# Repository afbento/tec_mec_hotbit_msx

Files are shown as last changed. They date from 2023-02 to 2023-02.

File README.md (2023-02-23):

# Teclado mecânico no Hotbit - MSX

Aqui mostro detalhes da adaptação de teclado de membrama para teclado com switches de teclado mecânico, feita para o microcomputador Hotbit HB-8000 (padrão MSX).

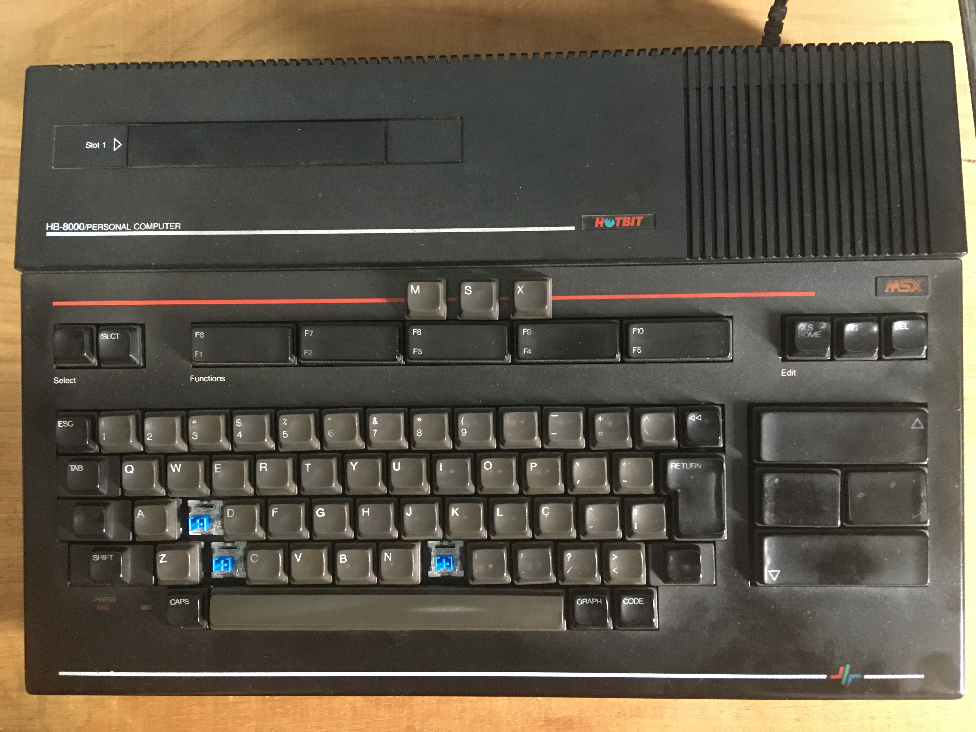
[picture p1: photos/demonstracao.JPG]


## Apresentação

ineficácia do teclado original (membrana). moda e desejo de muitos de um teclado mecânico pro Hotbit. compatibilidade quase ideal das teclas originais com switches (dust proof)

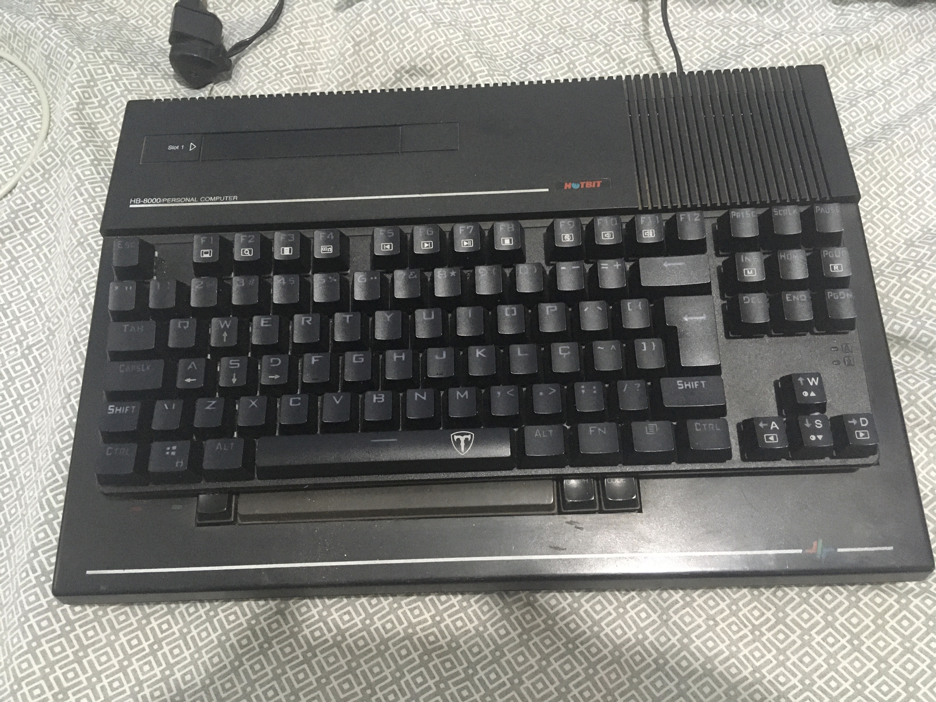
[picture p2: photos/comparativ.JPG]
 
Comparando o Hotbit com um teclado mecânico, doador das switches para esse projeto.

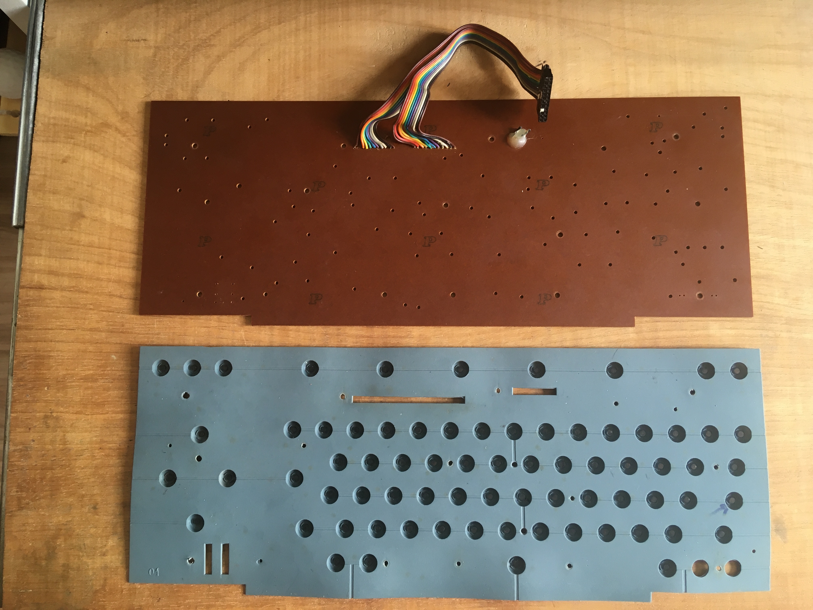
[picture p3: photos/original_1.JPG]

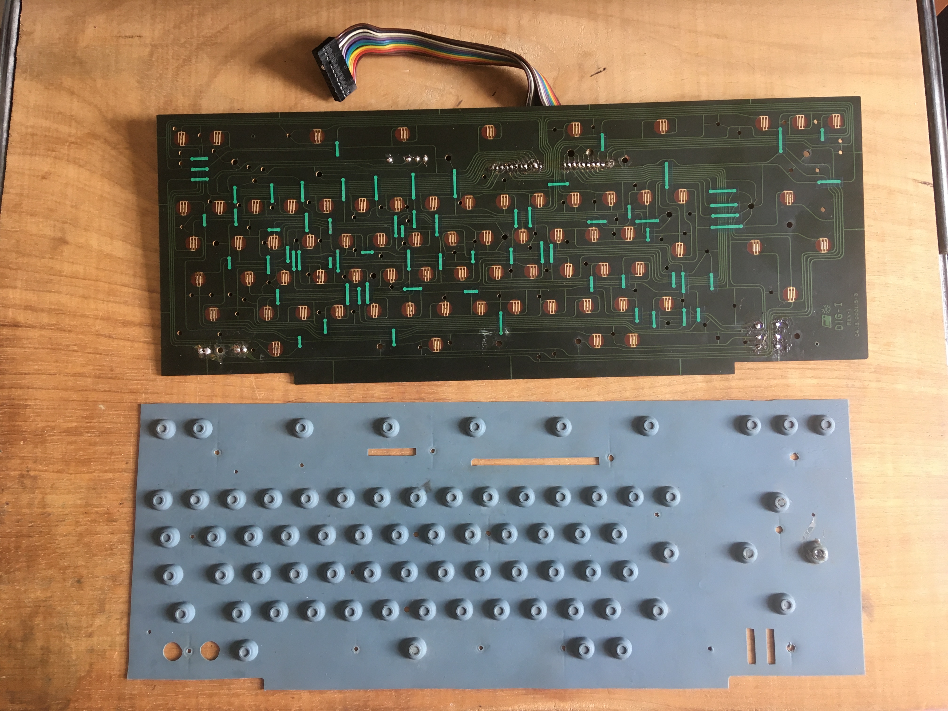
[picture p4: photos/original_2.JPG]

Membrana e PCB originais do Hotbit.

## Estudos

medidas e desenho feito em CAD como esboço pra possível corte em CNC, foi concluído um alto custo da confecção da base do teclado por esse método. além da confecção de PCB personalizada

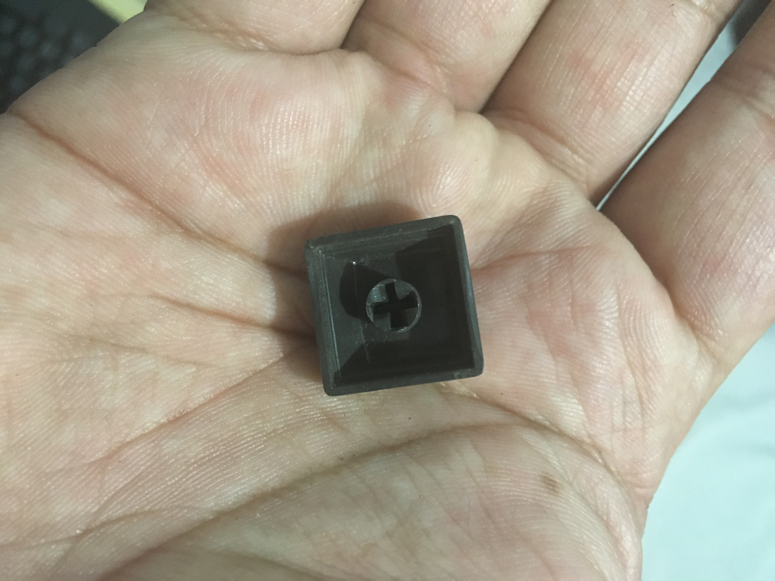
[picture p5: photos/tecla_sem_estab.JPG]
 Encaixe de tecla que não usa estabilizador

 
Conjunto tecla (sem estabilizador) e switch

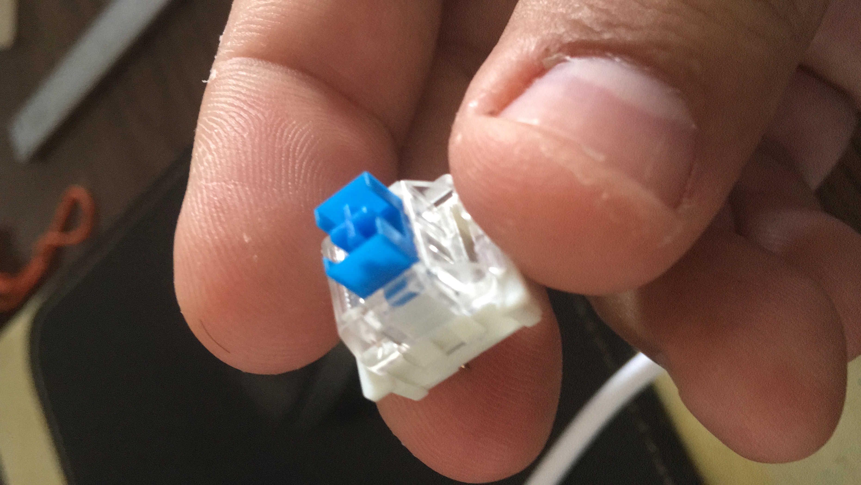
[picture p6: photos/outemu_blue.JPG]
 Switch Outemu Blue dust-proof

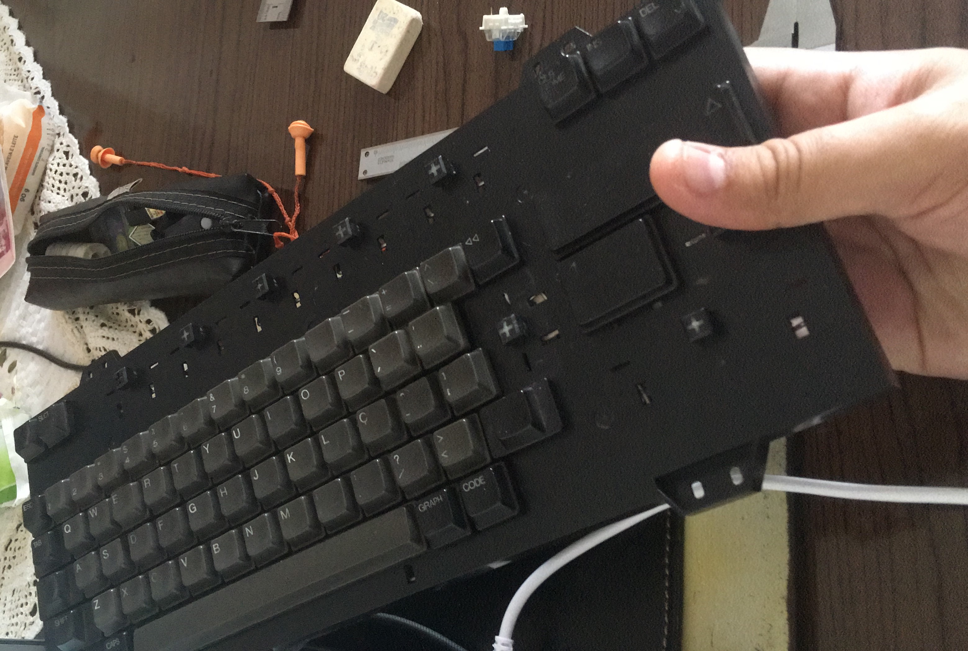
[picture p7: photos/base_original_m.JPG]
 Medindo a base original do teclado com paquímetro e no "olhômetro".

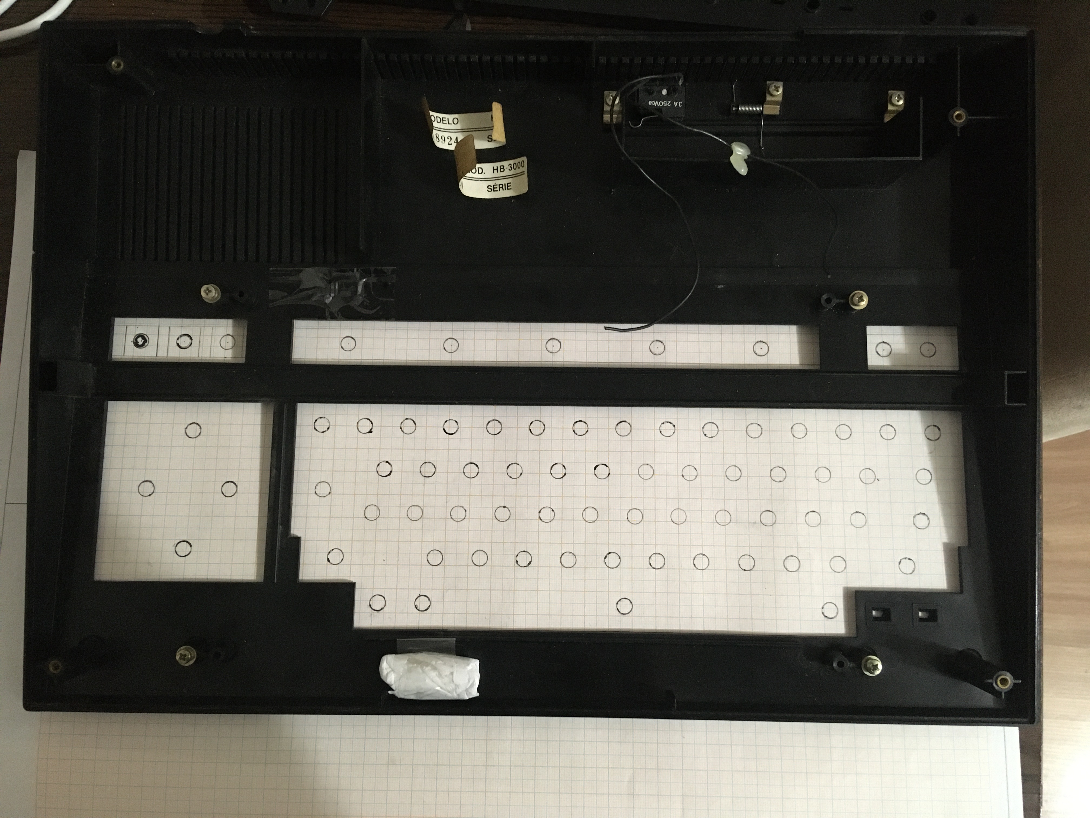
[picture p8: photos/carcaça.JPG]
 Carcaça do Hotbit junto com esboço feito com posição aproximada do centro de cada tecla

## Solução mais barata

idealização de um gabarito impresso em 3D que encaixa nos furos das teclas da base original do teclado do Hotbit, para execução de furos quadrados de 14mm x 14mm de maneira artesanal

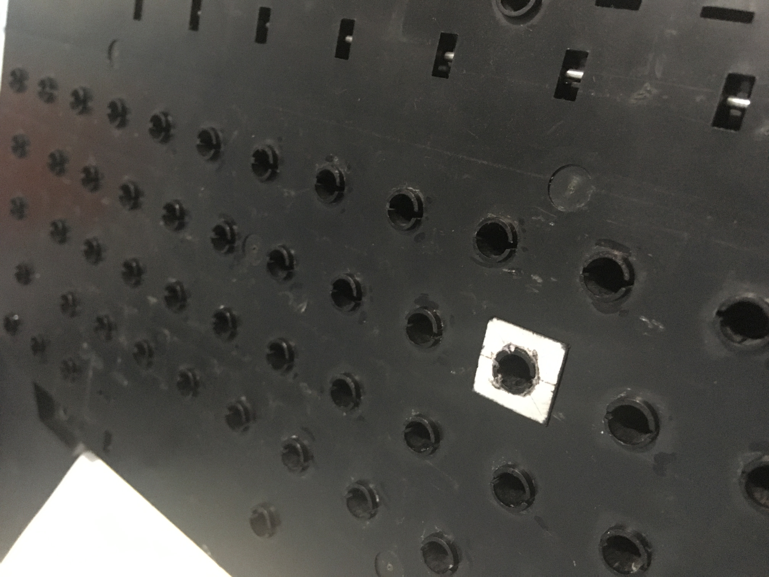
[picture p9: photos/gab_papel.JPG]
 Gabarito para traçar o furo quadrado em cada tecla, feito em papel (não foi utilizado)

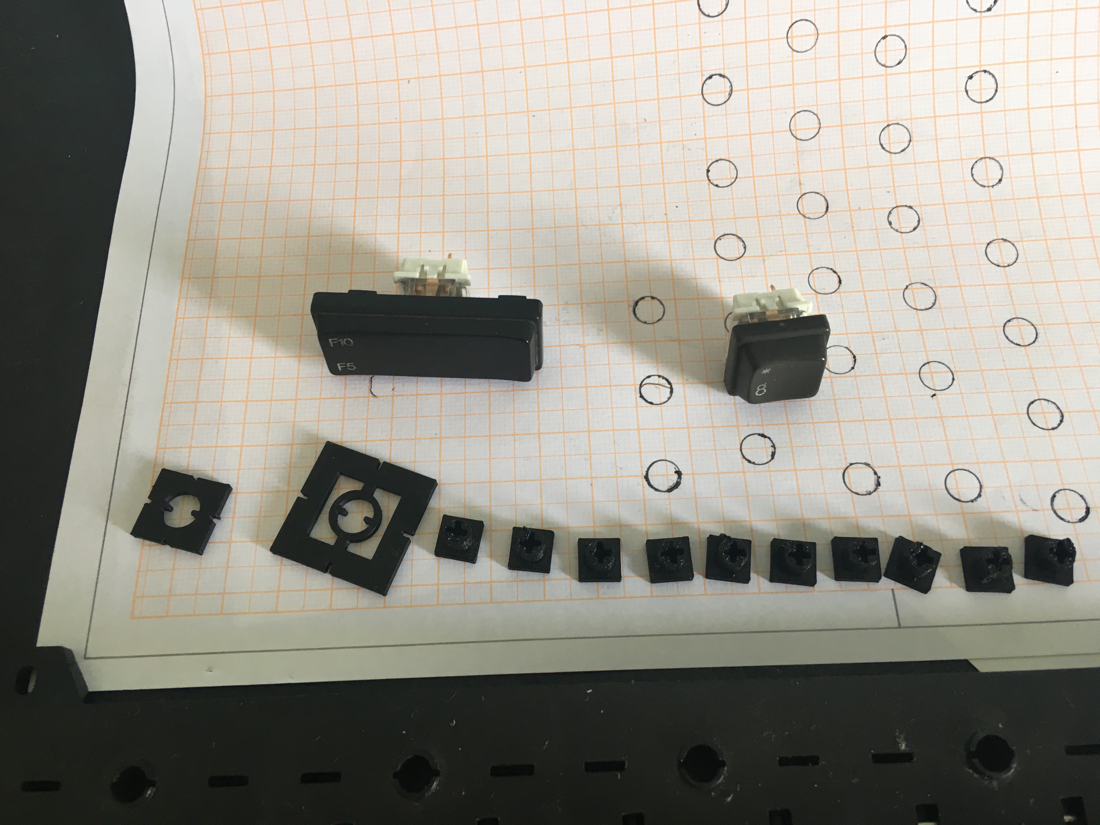
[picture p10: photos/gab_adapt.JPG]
 Gabaritos para os furos e adaptadores para uso nas teclas com estabilizadores.

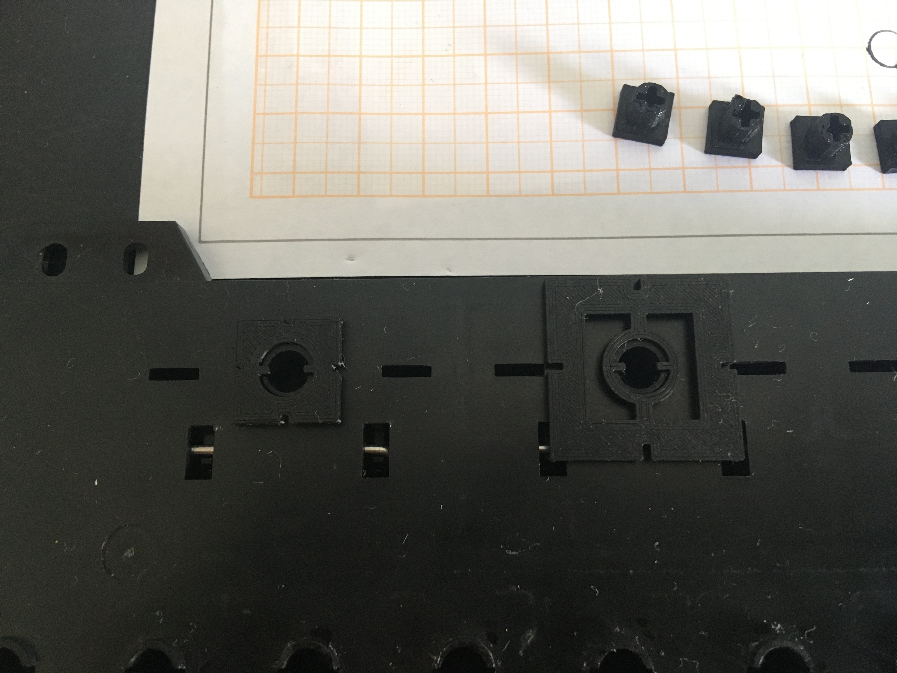
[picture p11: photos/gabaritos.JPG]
 Gabaritos encaixados em furos de tecla (somente o menor, da esquerda, foi utilizado)

## Procedimento

usar o gabarito traçando os limites do furo, utilizar "faca quente" pra corte grosseiro e lima para refinar o corte. uso de adaptador impresso em 3D nas teclas que usam estabilizadores e substituição parcial dos estabilizadores de plástico por de metal, com 2mm a mais de comprimento pra não interferir no movimento das switches. circuito "handwire" feito por questão de economia.

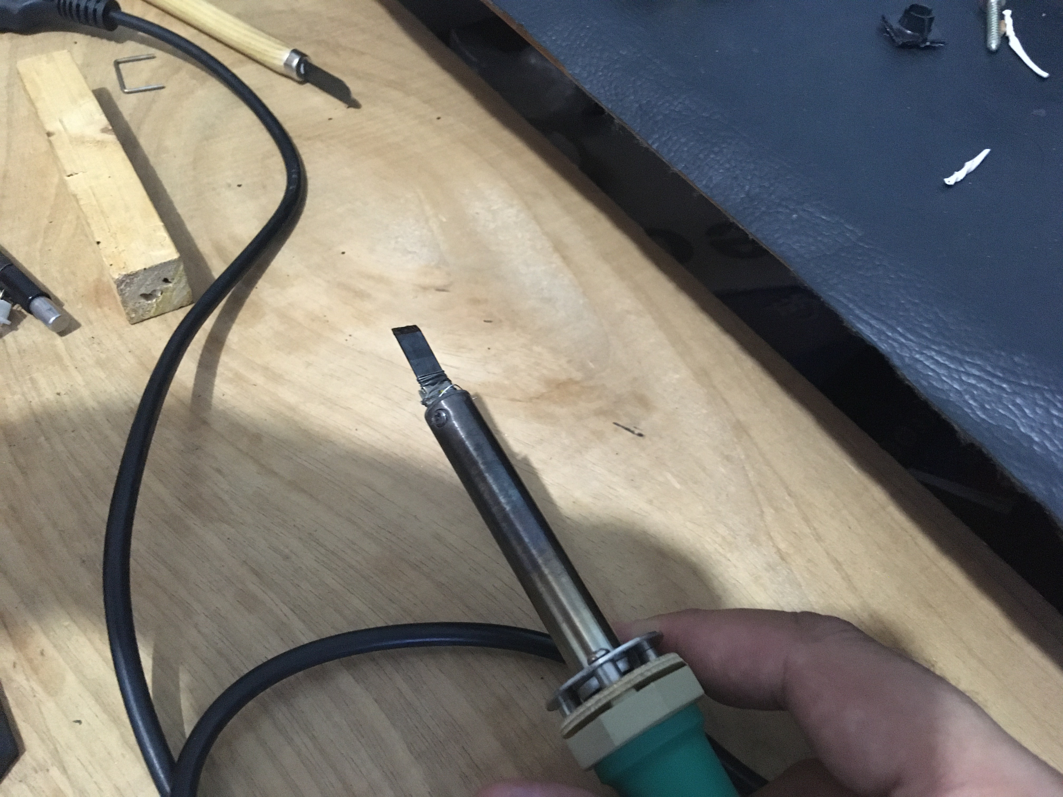
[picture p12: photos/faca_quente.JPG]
 Ferro de solda adaptado em "Faca quente" com uso de uma lâmina de formão para artesanato.

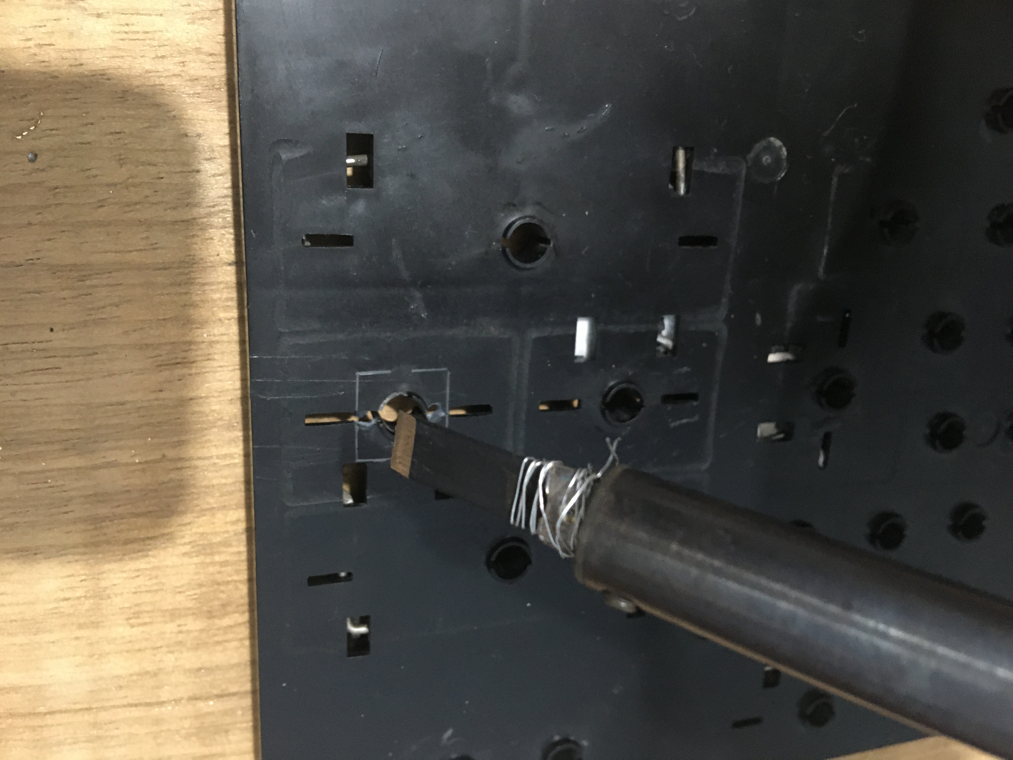
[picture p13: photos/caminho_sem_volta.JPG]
 Começando o primeiro furo.

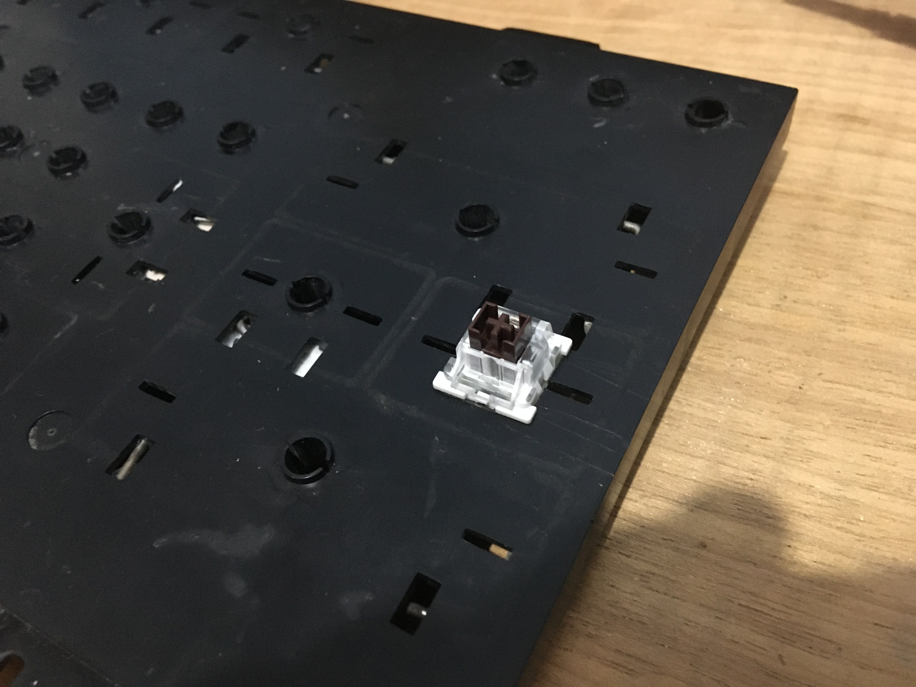
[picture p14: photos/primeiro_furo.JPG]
 Primeiro furo feito.

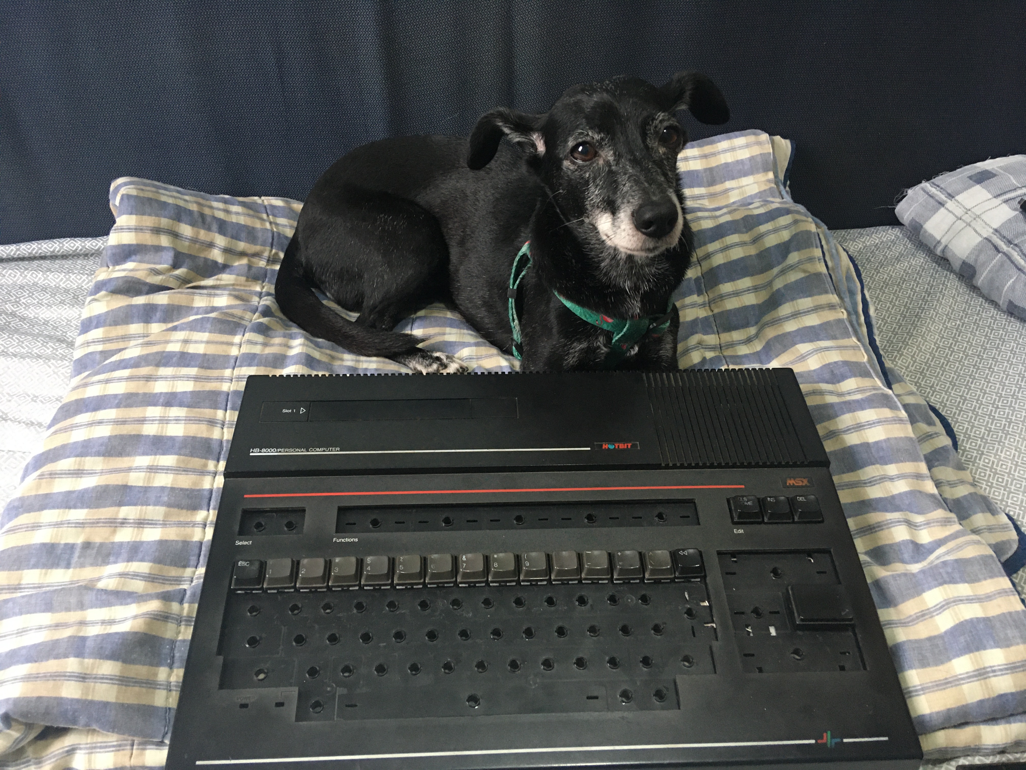
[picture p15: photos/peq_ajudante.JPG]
 Uma fileira de teclas foi feita... Verificando se ficou muito torto em relacao à carcaça com a minha pequena ajudante. :)

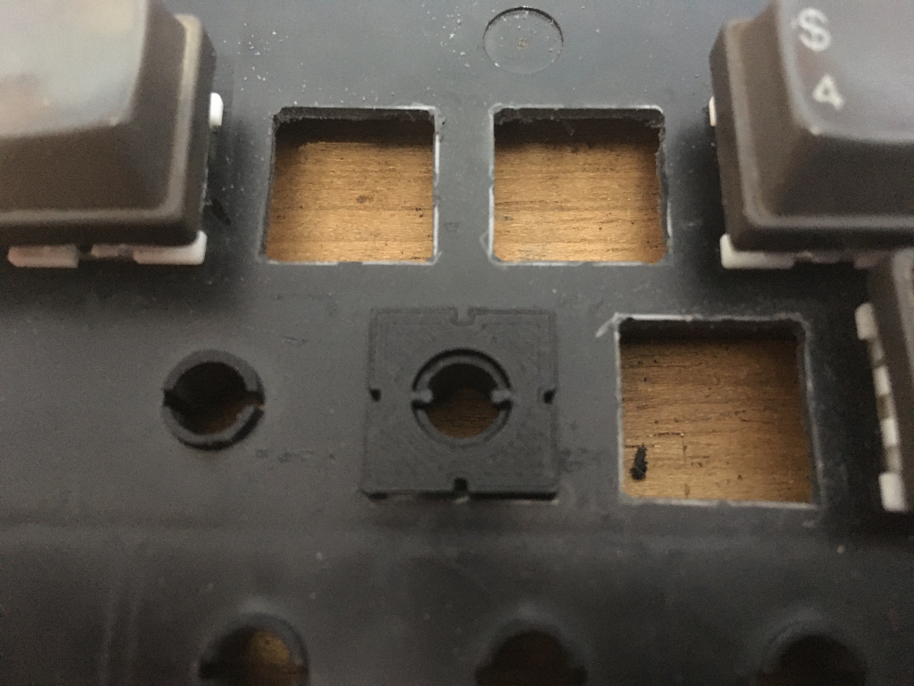
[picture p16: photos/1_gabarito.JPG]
 Encaixando o gabarito no furo.

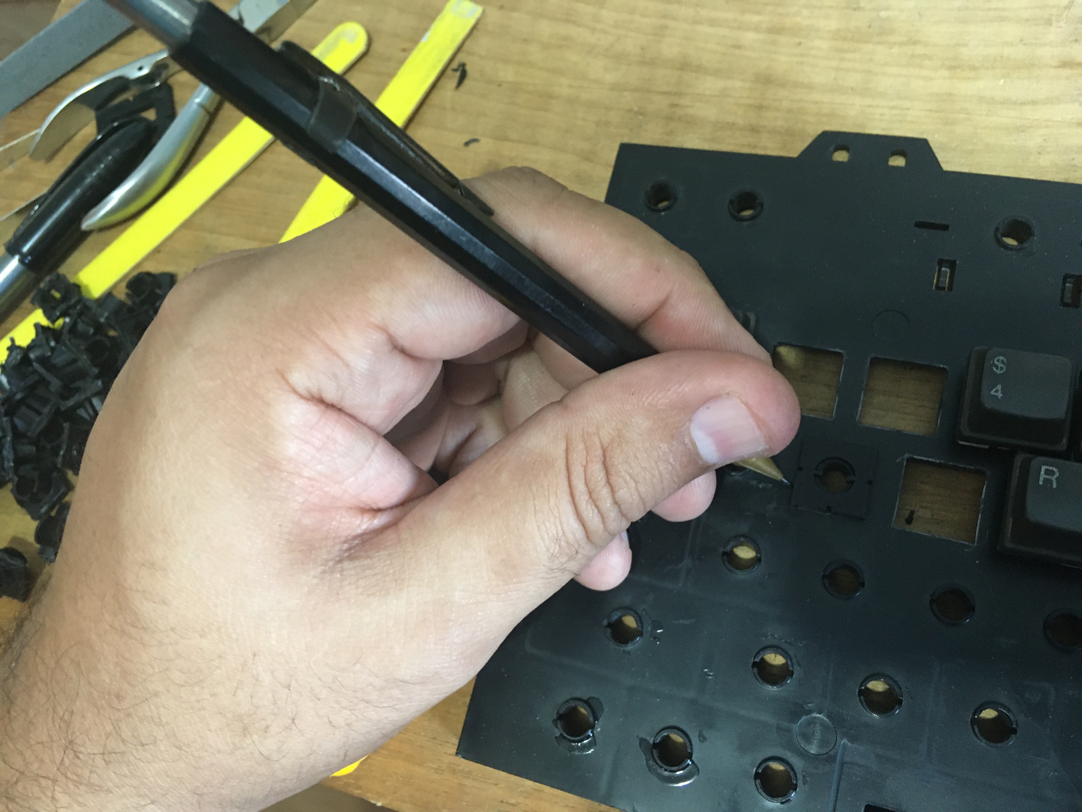
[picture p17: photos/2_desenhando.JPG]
 
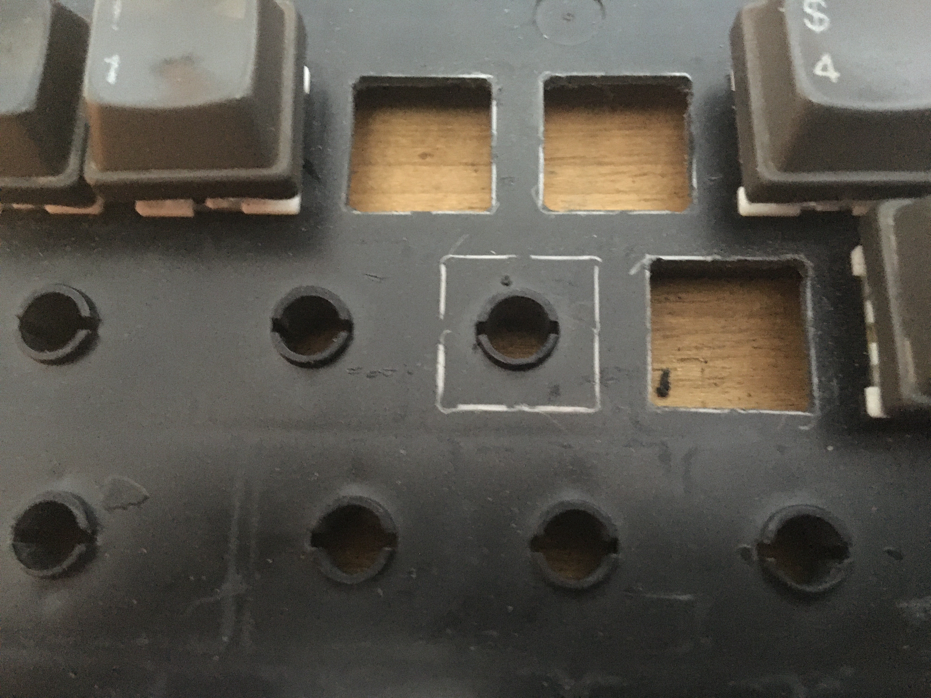
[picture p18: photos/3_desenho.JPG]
 Traçando onde cortar ao redor do gabarito.

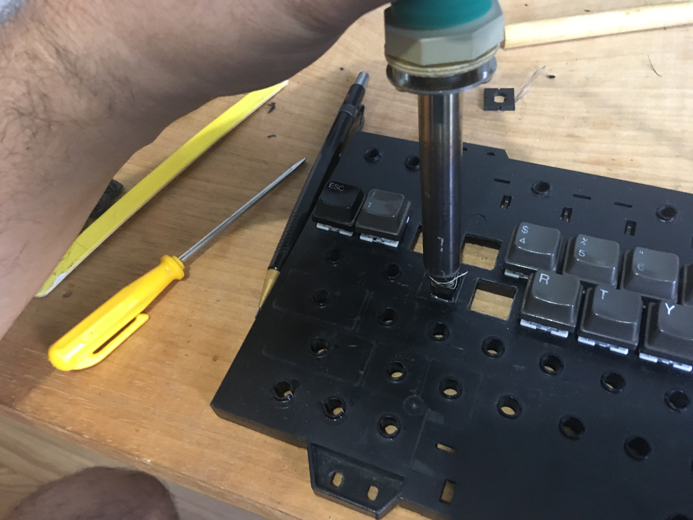
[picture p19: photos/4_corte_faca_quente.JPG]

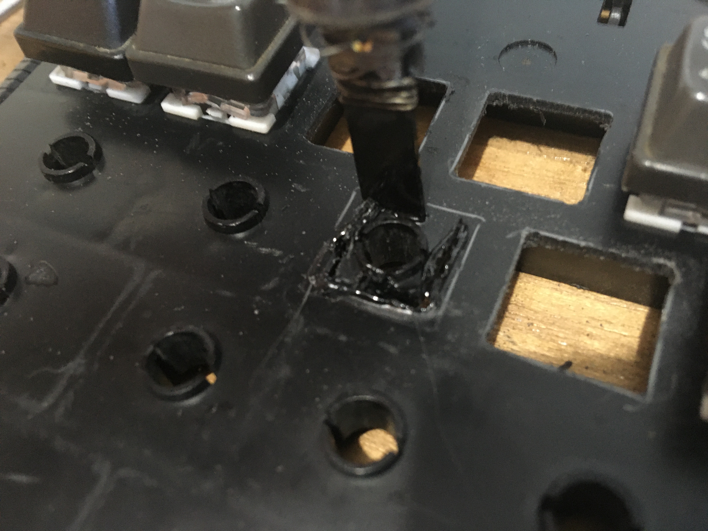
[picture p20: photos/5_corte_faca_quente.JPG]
 Corte grosseiro feito com a "faca quente"

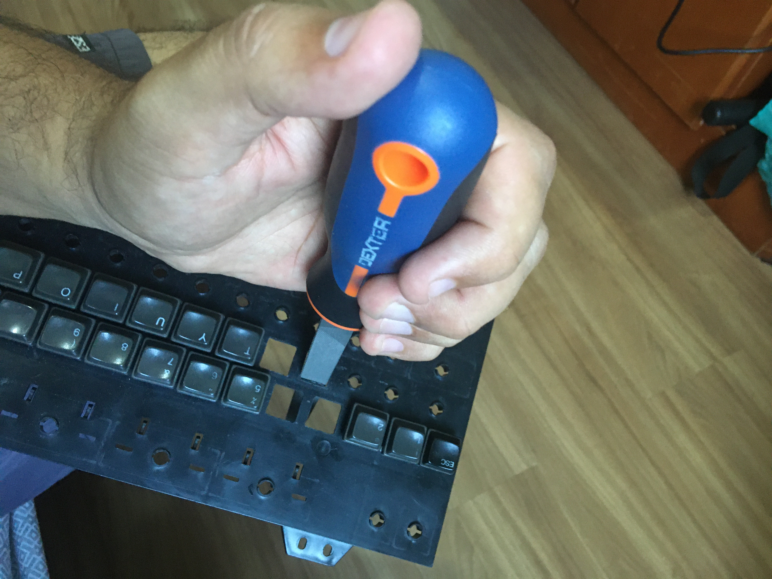
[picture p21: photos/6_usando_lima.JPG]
 Usando (literalmente nas coxas) uma lima para tirar rebarbas e refinar o corte.

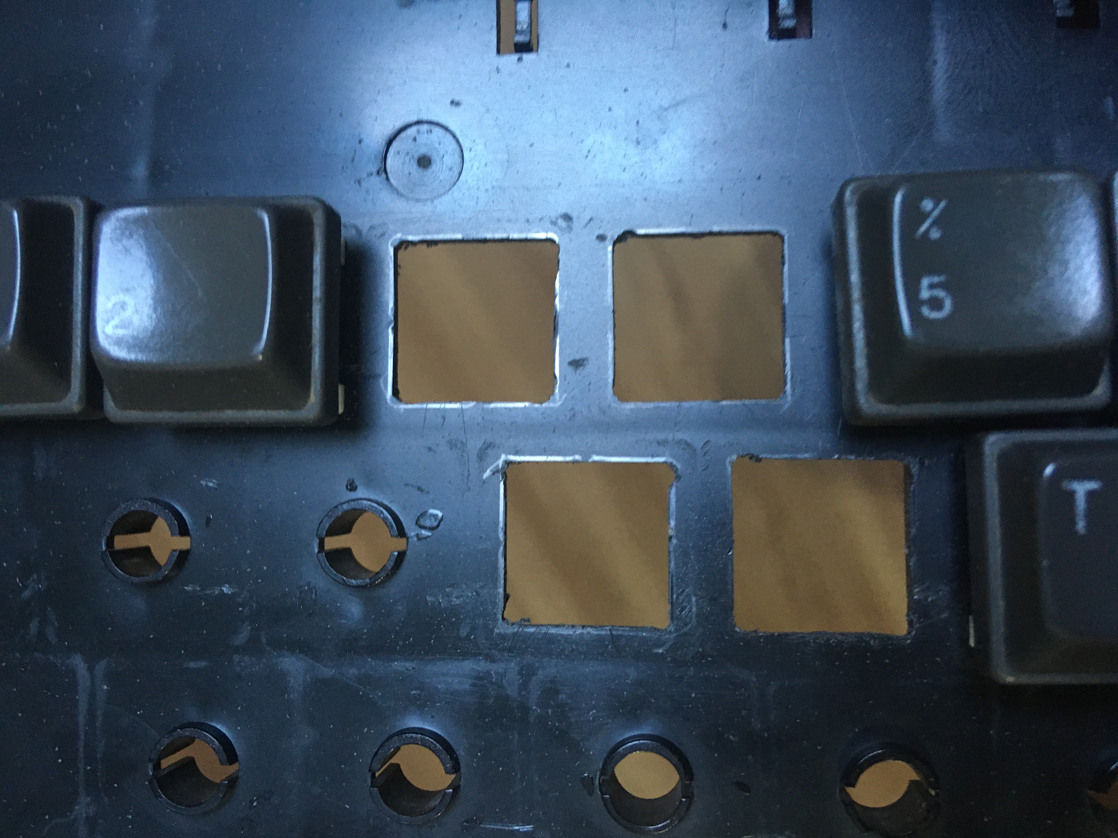
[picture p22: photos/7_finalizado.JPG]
 Furo finalizado.

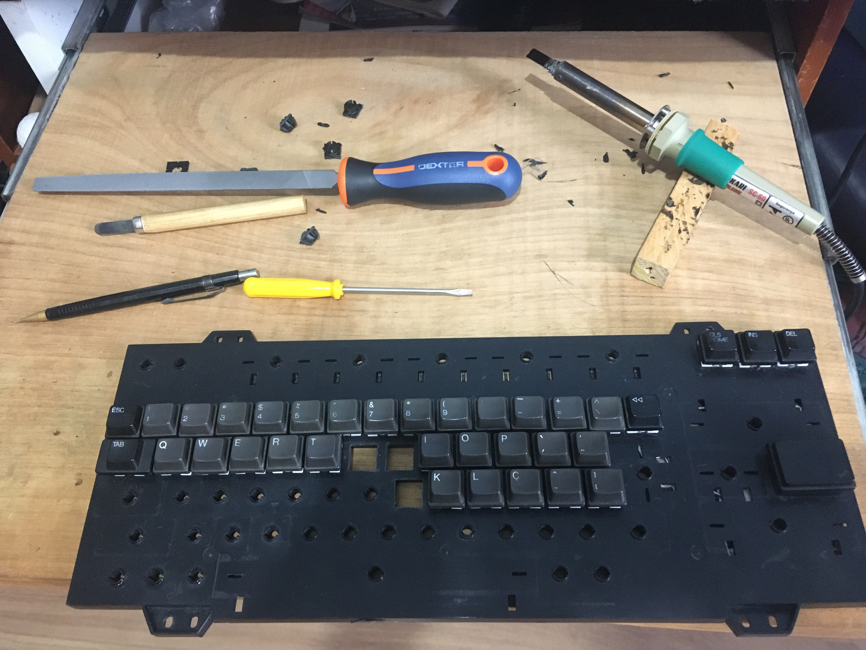
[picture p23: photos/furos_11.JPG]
 Só falta metade...

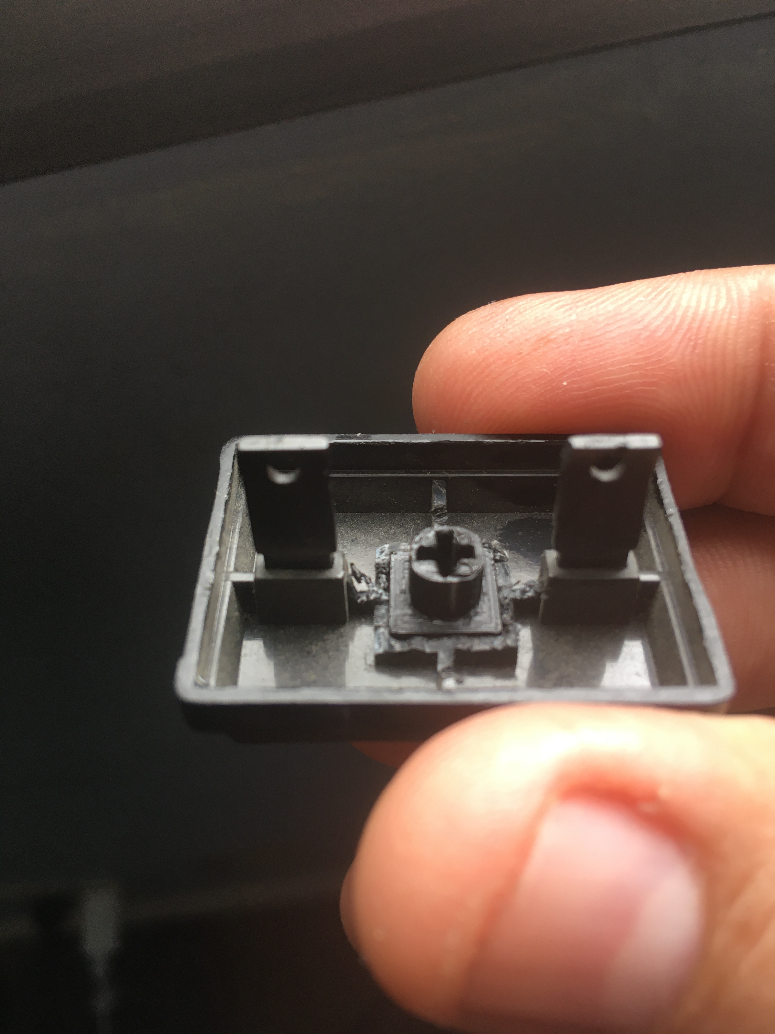
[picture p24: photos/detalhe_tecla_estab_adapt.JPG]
 
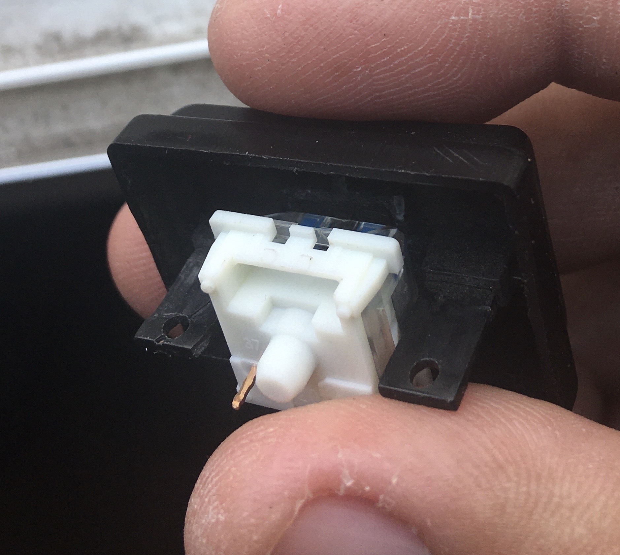
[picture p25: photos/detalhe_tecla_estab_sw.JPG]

Detalhe de ajuste feito nas tecla com estabilizador.

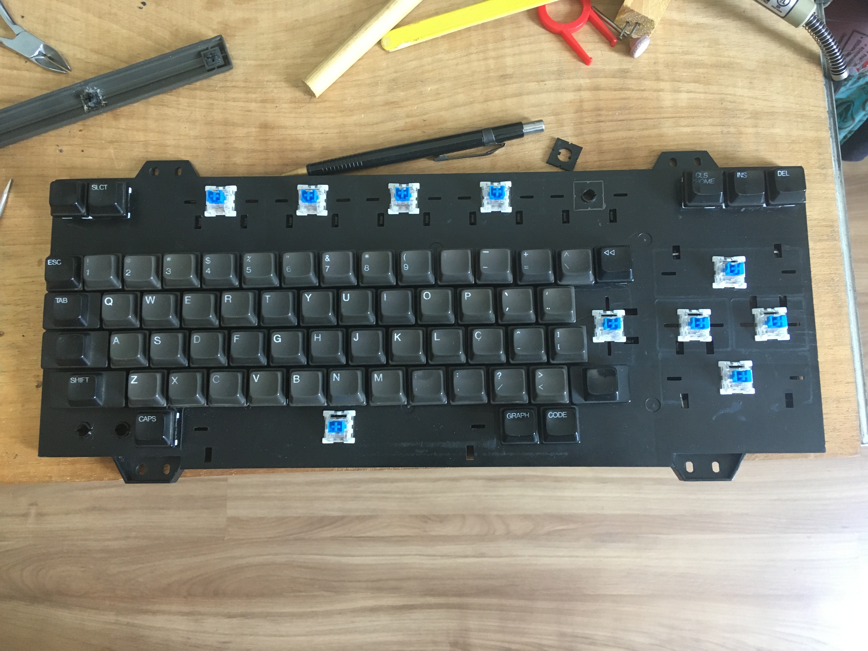
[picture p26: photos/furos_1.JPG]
 Falta o último furo.

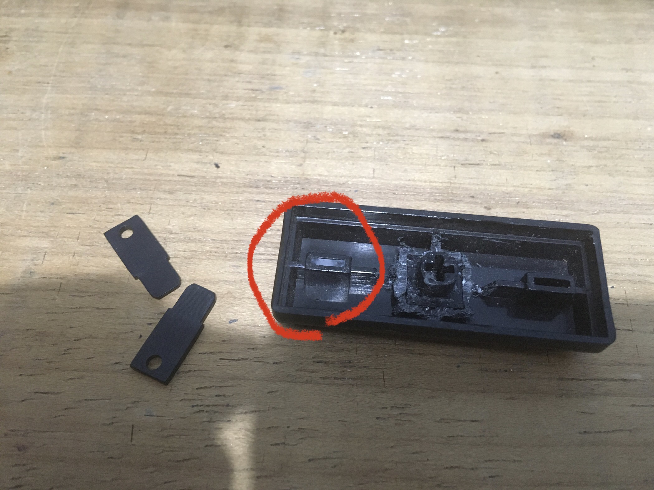
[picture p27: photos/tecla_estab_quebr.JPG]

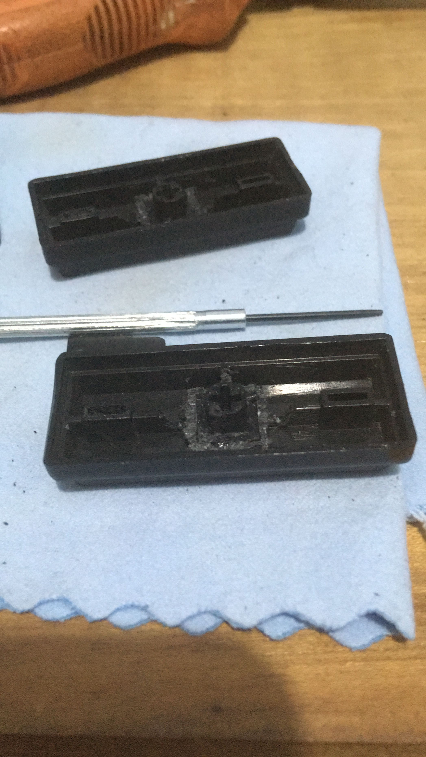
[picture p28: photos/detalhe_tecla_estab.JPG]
 Dica rápida: tirando pedaço de estabilizador quebrado com auxílio de uma broca de 0,8mm e uma "chavinha de relojoeiro"

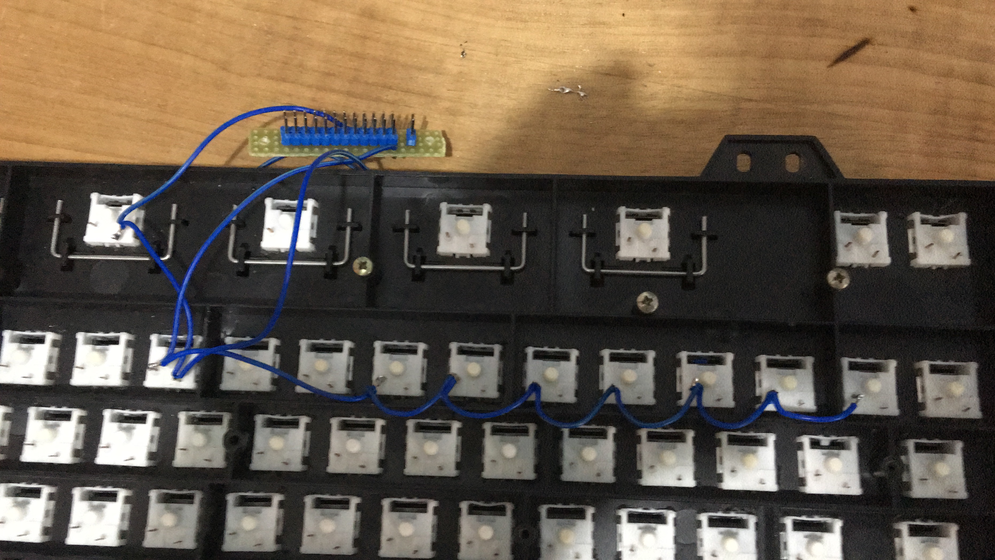
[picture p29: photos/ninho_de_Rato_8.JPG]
 Começando o circuito "handwired"... pra que gastar mandando fazer uma PCB num projeto artesanal??? :)

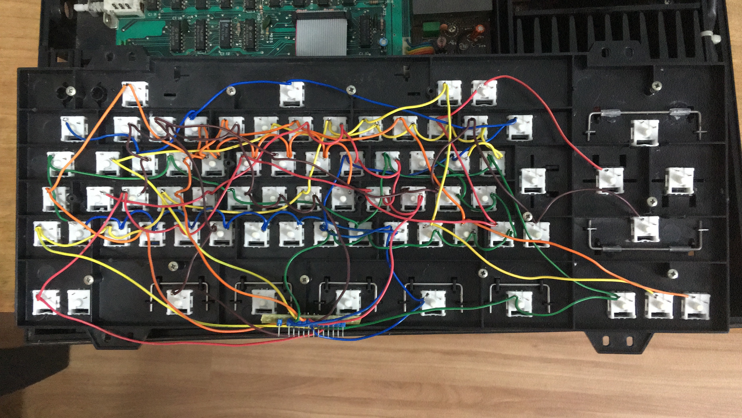
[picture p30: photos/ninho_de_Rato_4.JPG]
 Falta metade... isso foi mais agradável de fazer do que cortar plástico.

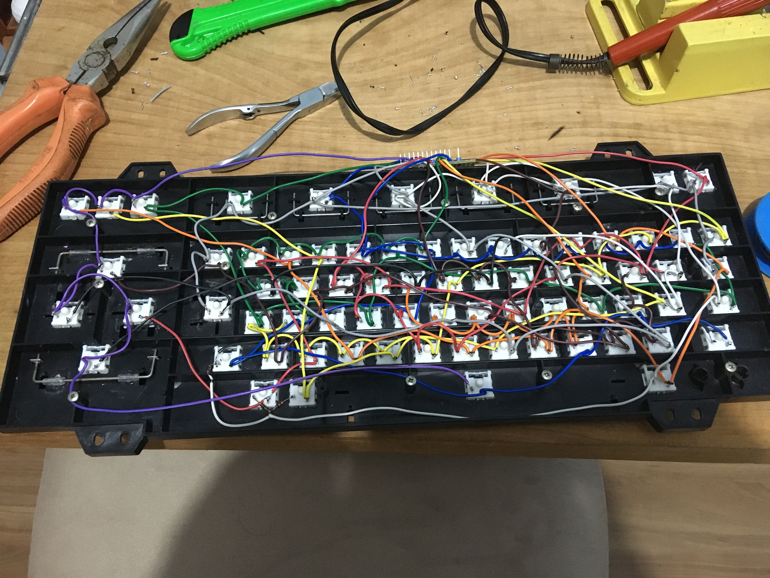
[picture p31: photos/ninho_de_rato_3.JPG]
 Matriz pronta. Falta prender o conector à base plastica, colocar também o conector da chave do slot e os leds.

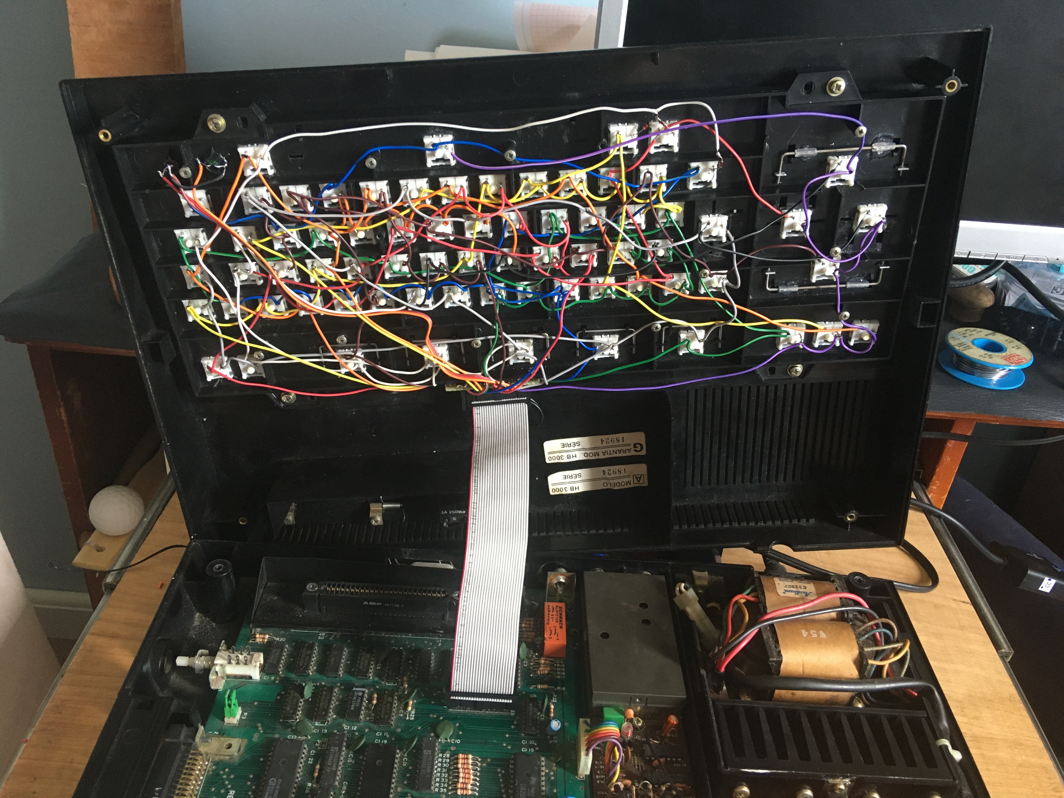
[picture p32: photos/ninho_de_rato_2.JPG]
 PRONTO!!! quer dizer... falta os esbilizadores das barra de espaço, return e cursor direto / esquerdo.

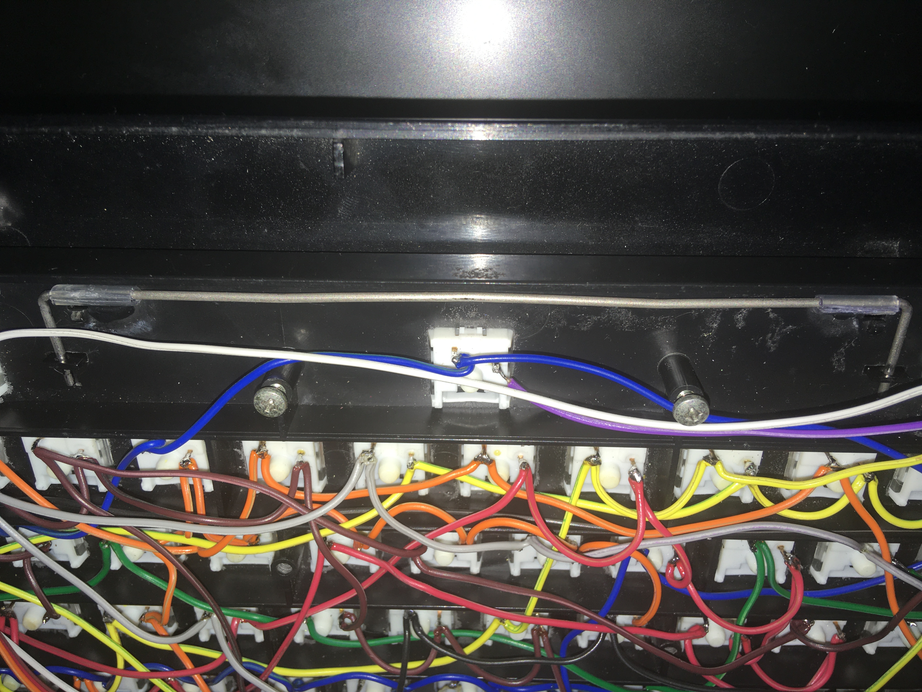
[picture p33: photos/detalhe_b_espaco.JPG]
 Detalhe da barra estabilizadora da barra de espaço.

## Soluções para alguns defeitos

lixar partes das teclas que não precisam que adaptação no encaixe com switches. para evitar "prender" teclas

## Como tornar o processo mais "profissional"

projeto de base nova em metal com furos cortados de maneira automatizada, e da PCB nova com soquetes "hotswap" para as switches

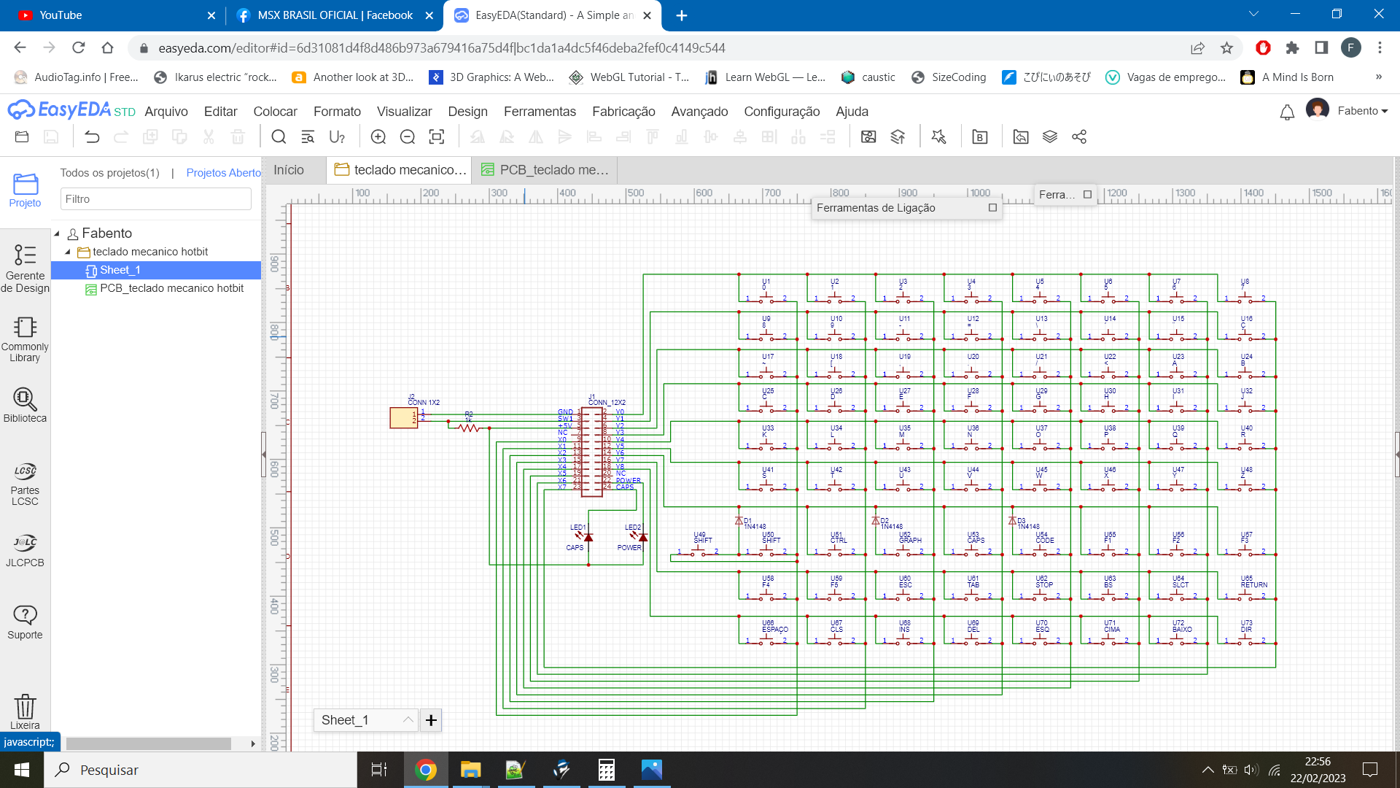
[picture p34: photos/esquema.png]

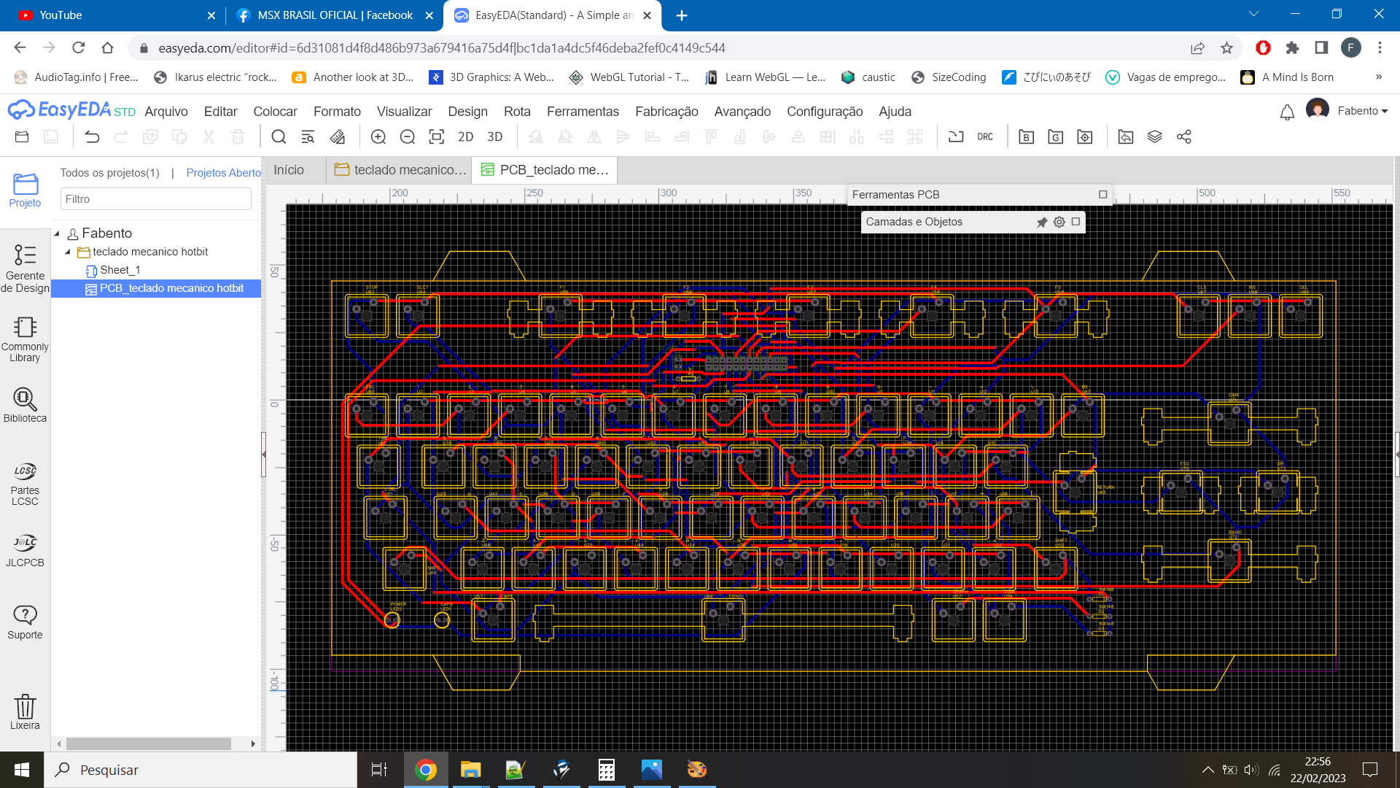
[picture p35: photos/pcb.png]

Esquema e PCB provisórios, feitos no EasyEDA.

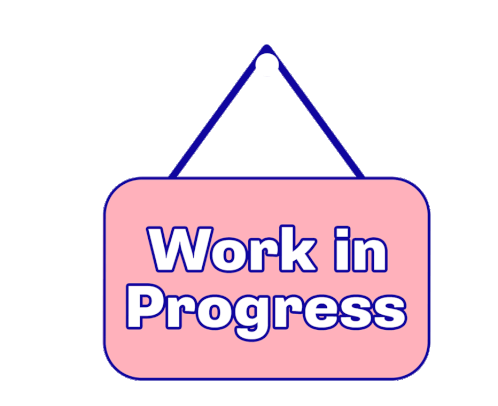
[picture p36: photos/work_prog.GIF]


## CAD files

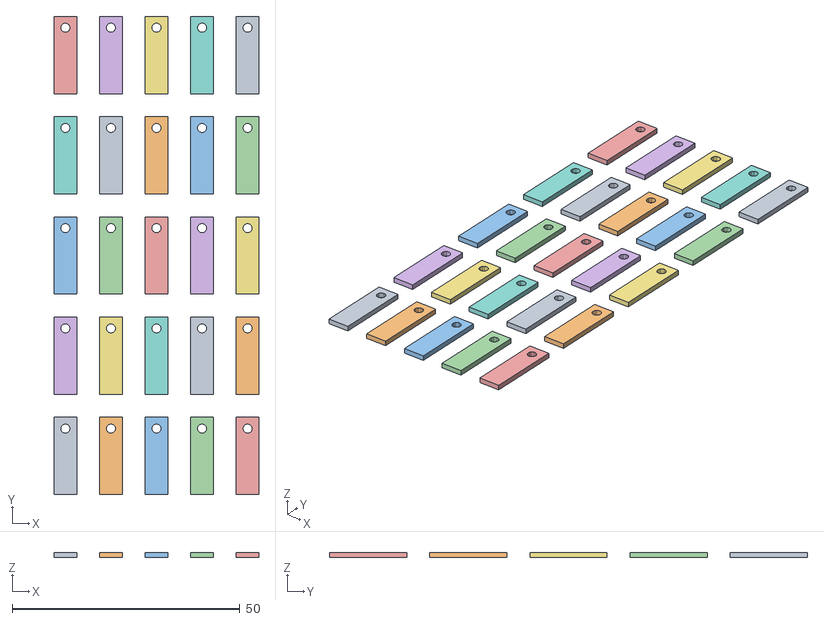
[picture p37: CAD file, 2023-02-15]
models/barrinha_estabilizador.obj
45.0 x 105.0 x 1.10

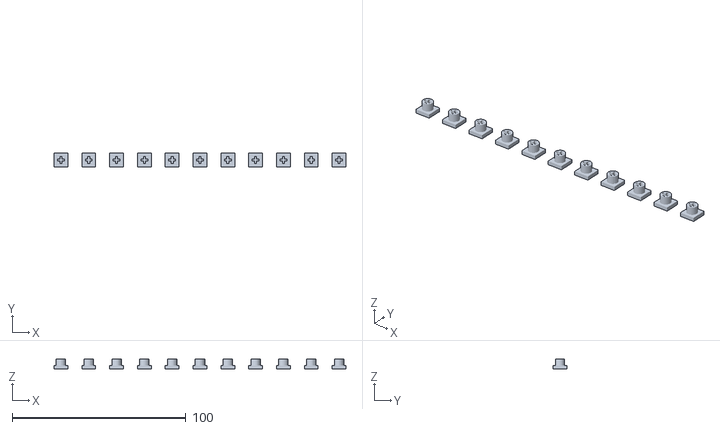
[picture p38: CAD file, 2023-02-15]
models/adaptador_onze.STL
168.0 x 8.00 x 6.00

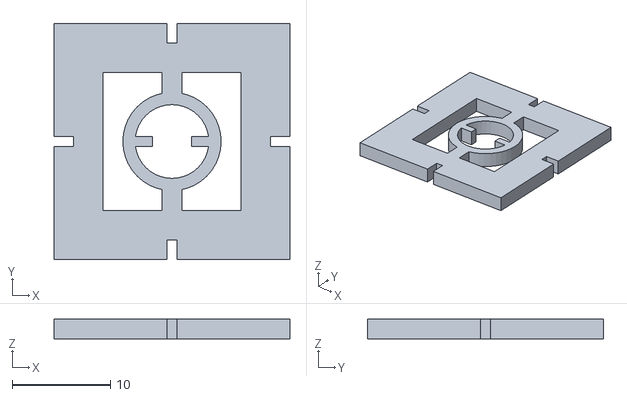
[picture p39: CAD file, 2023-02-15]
models/gabarito_furo_switch.STL
24.0 x 24.0 x 2.00

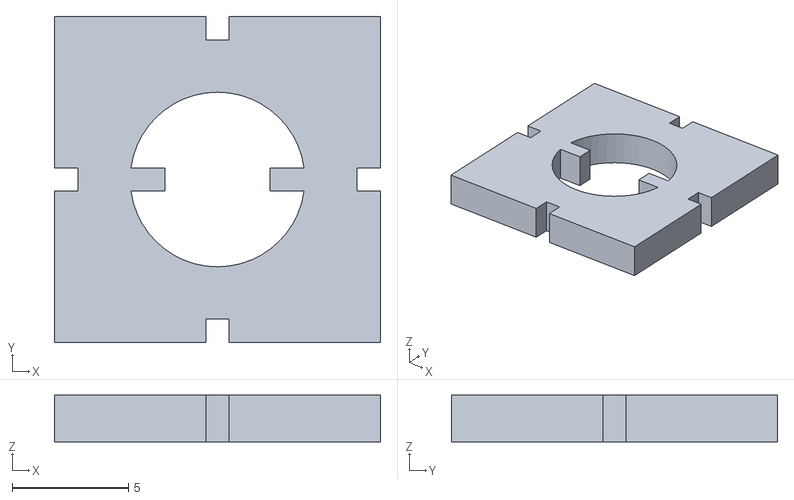
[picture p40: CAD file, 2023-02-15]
models/gabarito_furo_switch_v2.STL
14.0 x 14.0 x 2.00

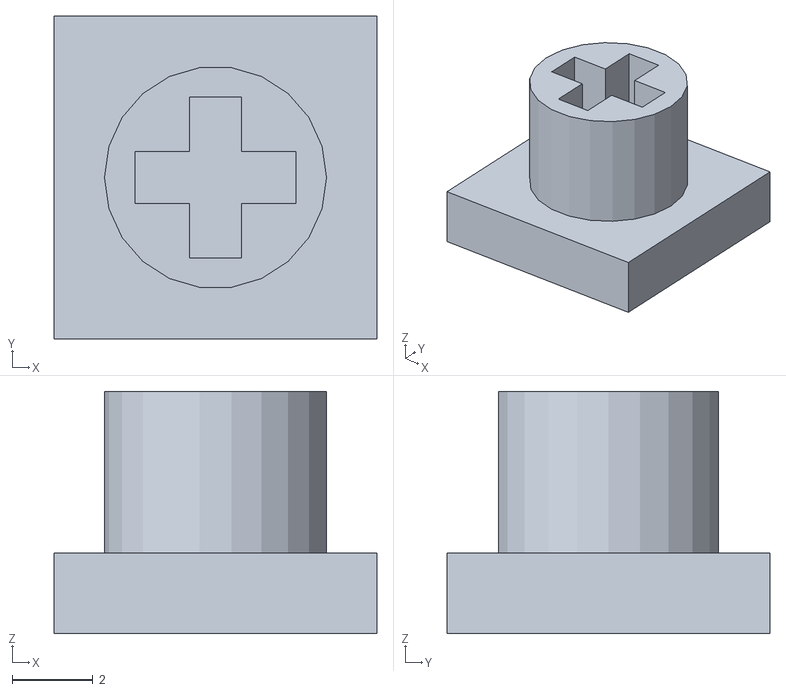
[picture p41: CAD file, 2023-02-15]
models/adaptador_unidade.STL
8.00 x 8.00 x 6.00

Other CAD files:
models/layout_base_teclado_hotbit_circuito_v2.dwg
models/adaptador_onze.obj
models/adaptador_unidade.obj
models/gabarito_furo_switch.obj
models/gabarito_furo_switch_v2.obj
